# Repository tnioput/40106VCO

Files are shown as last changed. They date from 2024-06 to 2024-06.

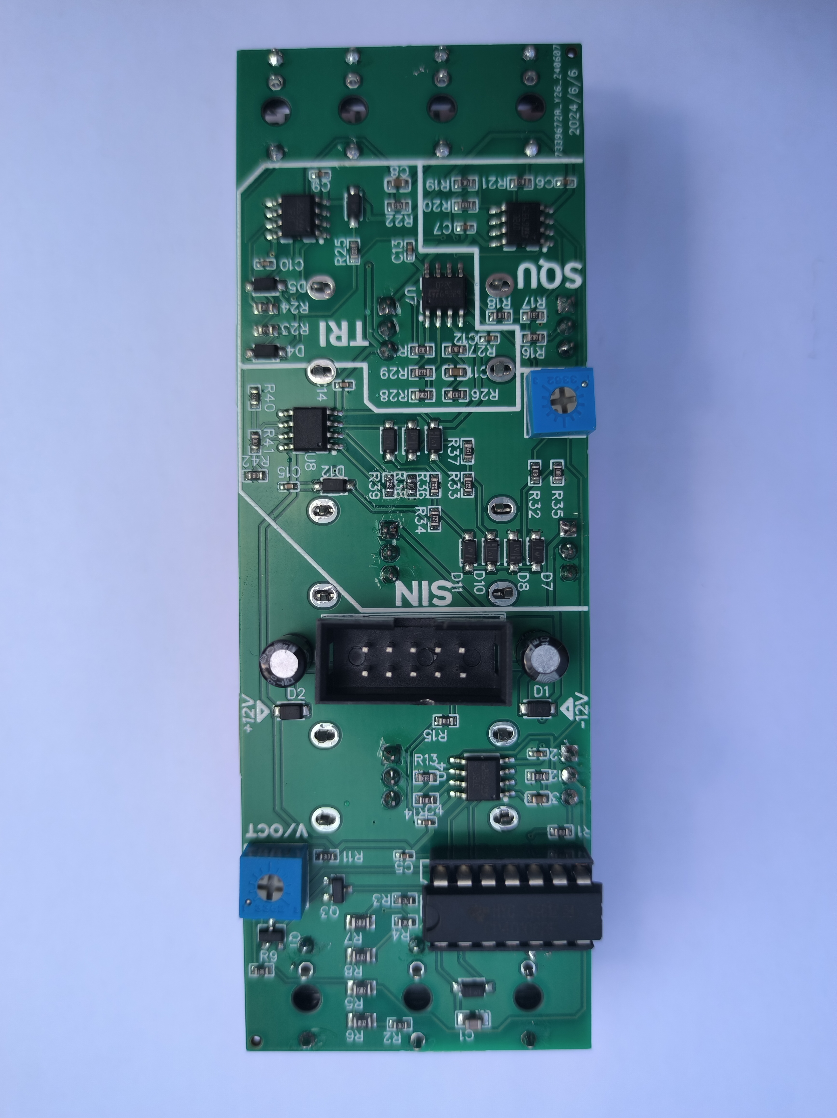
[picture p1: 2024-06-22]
backside.jpg

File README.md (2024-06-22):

# 40106VCO
- Moritz Klein-based vco tutorial series builds using SMT

- The PCB are drawn with easyEDA and uses the JLC base library.

示例图片

## <span style="font-size: larger;">Tips</span>
  
- If the triangle output waveform is not smooth, try to match R23,R24 to make them as consistent as possible.
- special attention：the height of the main board of the circuit is 115mm

## <span style="font-size: larger;">Inputs</span>

- PWM IN
- FM IN
- V/OCT IN
  
## <span style="font-size: larger;">Outputs</span>

- SIN OUT
- TRI OUT
- SAW OUT 
- PULSE OUT

## <span style="font-size: larger;">Controls</span>

- FM Depths
- FM Amount
- Frequency Coarse
- Frequency Fine
- PWM Width
- PWM Depths

## <span style="font-size: larger;">Power</span>

- +12 VDC @ 15 mA
- -12 VDC @ 15 mA
  
## <span style="font-size: larger;">Dimensions</span>

- Height: 3U
- Width: 8HP
- Depth: 25 mm

## <span style="font-size: larger;">YouTube </span>

- [Presentation](https://www.youtube.com/watch?v=QiLeUSpJTN0&t)

## License
This PCB layout is made available under a cc-by-sa-3.0 license.

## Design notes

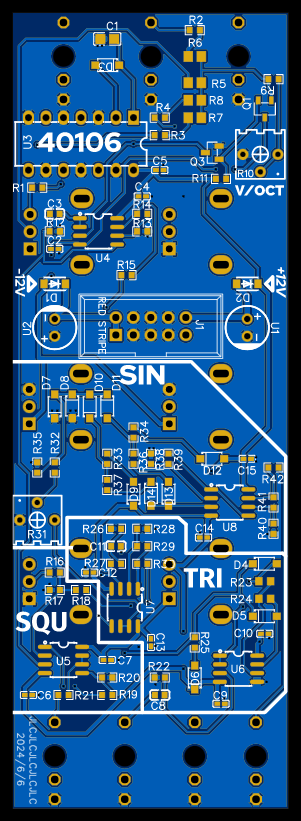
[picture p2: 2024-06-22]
Main board backside.png

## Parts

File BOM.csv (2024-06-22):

ID | Name | Designator | Footprint | Quantity | Manufacturer Part | Manufacturer | Supplier | Supplier Part | Price | Pins | JLCPCB Part Class | Resistance(Ohms)
1 | 10kΩ | R38,R40 | R0603 | 2 | 0603WAF1002T5E | UNI-ROYAL(厚声) | LCSC | C25804 | 0.0056 | 2 | Basic Part
2 | 33kΩ | R39,R41,R13 | R0603 | 3 | 0603WAF3302T5E | UNI-ROYAL(厚声) | LCSC | C4216 | 0.0061 | 2 | Basic Part
3 | TL072CDT | U4,U5,U6,U7,U8 | SOIC-8_L5.0-W4.0-P1.27-LS6.0-BL | 5 | TL072CDT | ST(意法半导体) | LCSC | C6961 | 1.1838 | 8 | Basic Part
4 | 2.2nF | C1 | C0805 | 1 | CL21C222JBFNNNE | SAMSUNG(三星) | LCSC | C28260 | 0.1964 | 2 | Basic Part
5 | 100nF | C2,C4,C5,C6,C7,C9,C10,C12,C13,C14,C15 | C0402 | 11 | CL05B104KB54PNC | SAMSUNG(三星) | LCSC | C307331 | 0.0306 | 2 | Basic Part
6 | 1uF | C3,C8,C11 | C0603 | 3 | CL10A105KB8NNNC | SAMSUNG(三星) | LCSC | C15849 | 0.0285 | 2 | Basic Part
7 | 1N4148W_C81598 | D3,D4,D5,D6,D7,D8,D9,D10,D11,D12,D13,D14 | SOD-123F_L2.7-W1.6-LS3.8-RD | 12 | 1N4148W | ST(先科) | LCSC | C81598 | 0.0712 | 2 | Basic Part
8 | Synth_power_2x5 | J1 | POWER_HEADER | 1 |  |  |  |  |  | 10
9 | S8550_C105432 | Q1 | SOT-23-3_L2.9-W1.6-P1.90-LS2.8-BR | 1 | S8550 | CJ(江苏长电/长晶) | LCSC | C105432 | 0.0912 | 3 | Basic Part
10 | 100kΩ | R1,R2,R4,R12,R14,R18,R19 | R0603 | 7 | 0603WAF1003T5E | UNI-ROYAL(厚声) | LCSC | C25803 | 0.0061 | 2 | Basic Part
11 | 1MΩ | R3,R11 | R0603 | 2 | 0603WAF1004T5E | UNI-ROYAL(厚声) | LCSC | C22935 | 0.0063 | 2 | Basic Part
12 | 1.5kΩ | R9 | R0603 | 1 | 0603WAF1501T5E | UNI-ROYAL(厚声) | LCSC | C22843 | 0.0061 | 2 | Basic Part
13 | 1kΩ | R15,R21,R27,R30,R32,R35,R42 | R0603 | 7 | 0603WAF1001T5E | UNI-ROYAL(厚声) | LCSC | C21190 | 0.0062 | 2 | Basic Part
14 | 68kΩ | R16,R20,R28 | R0603 | 3 | 0603WAF6802T5E | UNI-ROYAL(厚声) | LCSC | C23231 | 0.0061 | 2 | Basic Part
15 | 15kΩ | R17 | R0603 | 1 | 0603WAF1502T5E | UNI-ROYAL(厚声) | LCSC | C22809 | 0.0065 | 2 | Basic Part
16 | 200kΩ | R22,R25,R26 | R0603 | 3 | 0603WAF2003T5E | UNI-ROYAL(厚声) | LCSC | C25811 | 0.0062 | 2 | Basic Part
17 | 82kΩ | R29 | R0603 | 1 | 0603WAF8202T5E | UNI-ROYAL(厚声) | LCSC | C23254 | 0.0062 | 2 | Basic Part
18 | 22kΩ | R33,R34 | R0603 | 2 | 0603WAF2202T5E | UNI-ROYAL(厚声) | LCSC | C31850 | 0.0062 | 2 | Basic Part
19 | 560Ω | R36,R37 | R0603 | 2 | 0603WAF5600T5E | UNI-ROYAL(厚声) | LCSC | C23204 | 0.0062 | 2 | Basic Part
20 | KNTC0805/10KF3950 | R5,R6,R7,R8 | R0805 | 4 | KNTC0805/10KF3950 | KUU | LCSC | C2892549 | 0.2442 | 2 | Extended Part
21 | 1kΩ | R10 | RES-ADJ-TH_3362P | 1 | 3362P-1-102LF | BOURNS | LCSC | C58161 | 1.825 | 3 | Extended Part | 1K
22 | 10kΩ | R31 | RES-ADJ-TH_3362P | 1 | 3362P-1-103 | BOCHEN(博晨) | LCSC | C118956 | 0.8442 | 3 | Extended Part | 10K
23 | 10kΩ | R23,R24 | R0603 | 2 | RC0402FR-0710KL | YAGEO(国巨) | LCSC | YAGEO(国巨) |  | 2 | Extended Part
24 | CD40106 | U3 | PDIP-14_L19.3-W6.4-P2.54-LS7.6-BL | 1 | CD40106BE | HGSEMI(华冠) | LCSC | C507171 | 1.0223 | 14 | Extended Part
25 | MMBT3904-C20526 | Q3 | SOT-23-3_L2.9-W1.3-P1.90-LS2.4-BR | 1 | MMBT3904 | CJ(江苏长电/长晶) | LCSC | C20526 | 0.0613 | 3 | Basic Part
26 | SM4007PL | D1,D2 | SOD-123F_L2.8-W1.8-LS3.7-RD | 2 | SM4007PL | MDD | LCSC | C64898 | 0.045 | 2 | Basic Part
27 | 10uF | U1,U2 | CAP-TH_BD6.3-P2.50-D0.5-FD | 2 | MHT10UF400V87EC0217 | KNSCHA(科尼盛) | LCSC | C3034527 | 0.6083 | 2 | Extended Part
28 | 50K | POT-FINE,POT-COARSE | POTENTIOMETER_RV09 | 2 | R09-B502-3P 6mm | ReliaPro |  | C10545 | 0.99 | 5
29 | 1M | POT-ATT,POT-AMOUNT | POTENTIOMETER_RV09 | 2 | R09-B502-3P 6mm | ReliaPro |  | C10545 | 0.99 | 5
30 | PJ301_THONKICONN3 | J-FM,J-PWM,J-V/OCT,PULSE,SAW,SIN,TRI | WQP_PJ_301M3 | 7 |  |  |  |  |  | 3
31 | 250k | POT-DEPTHS | POTENTIOMETER_RV09 | 1 | R09-B502-3P 6mm | ReliaPro |  | C10545 | 0.99 | 5
32 | 100K | POT-WIDTH | POTENTIOMETER_RV09 | 1 | R09-B502-3P 6mm | ReliaPro |  | C10545 | 0.99 | 5

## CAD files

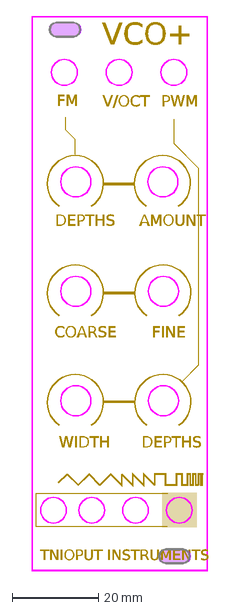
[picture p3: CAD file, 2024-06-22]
VCO+_PANEL.dxf
TNIOPUT INSTRUMENTS
VCO+
V/OCT
FM
PWM
AMOUNT
DEPTHS
WIDTH
COARSE
FINE

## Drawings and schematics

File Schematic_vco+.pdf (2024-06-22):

## TRI TO SIN

## SAW TO TRI

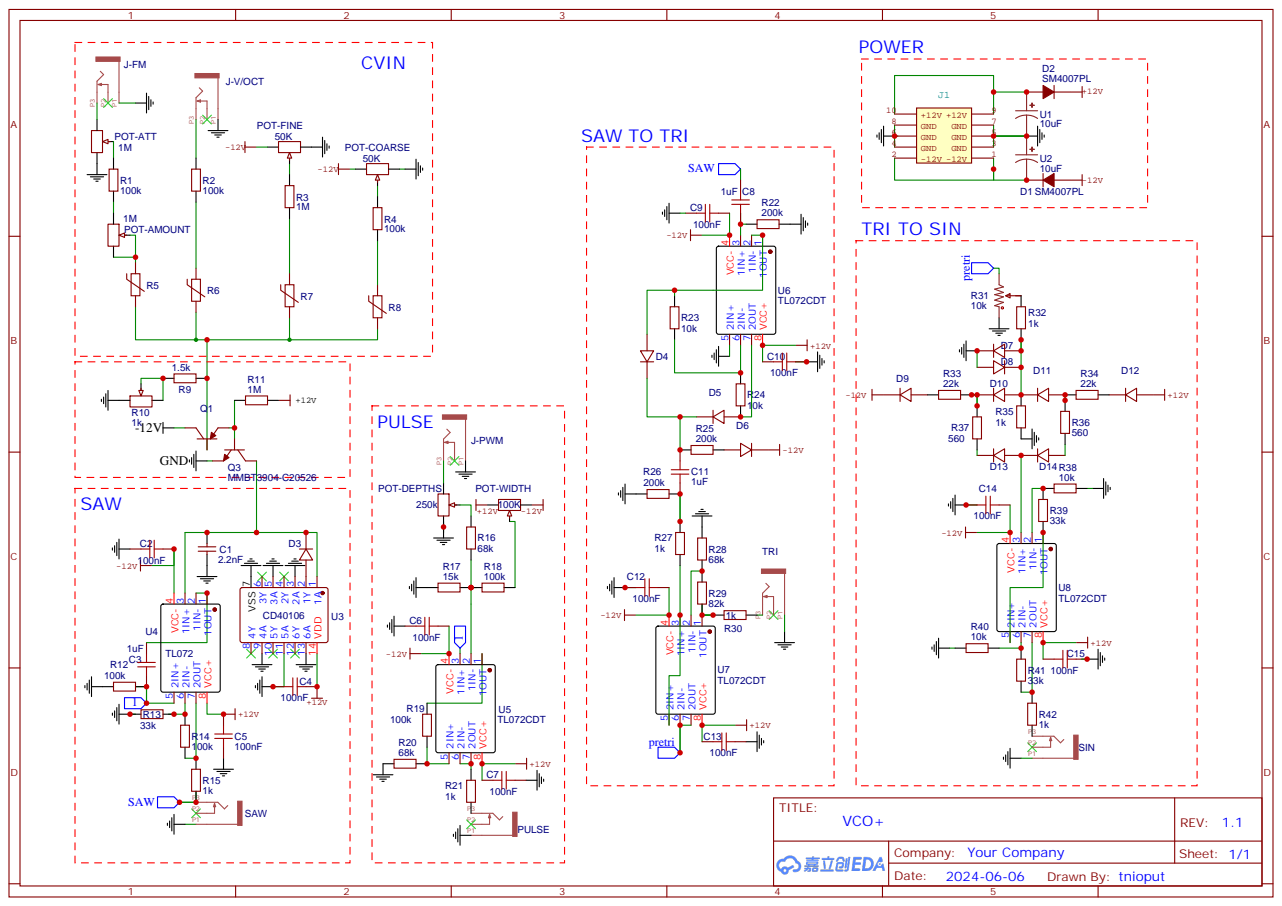
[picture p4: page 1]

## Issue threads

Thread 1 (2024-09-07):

无法在嘉立创EDA打开“Gerber_PCB_VCO+.zip”文件？

xO-xN, 2024-09-07:
想要让嘉立创做这个项目的PCB，“Gerber_PCB_VCO+.zip”文件可以正常读取下单，但是在SMT贴片时没有可提供的”位置文件“。尝试用嘉立创EDA打开“Gerber_PCB_VCO+.zip”文件（文件-导入-嘉立创EDA），显示错误：”选择导入的文件格式不正确或不匹配当前类型，请重新选择导入。“

如何得到位置文件？
